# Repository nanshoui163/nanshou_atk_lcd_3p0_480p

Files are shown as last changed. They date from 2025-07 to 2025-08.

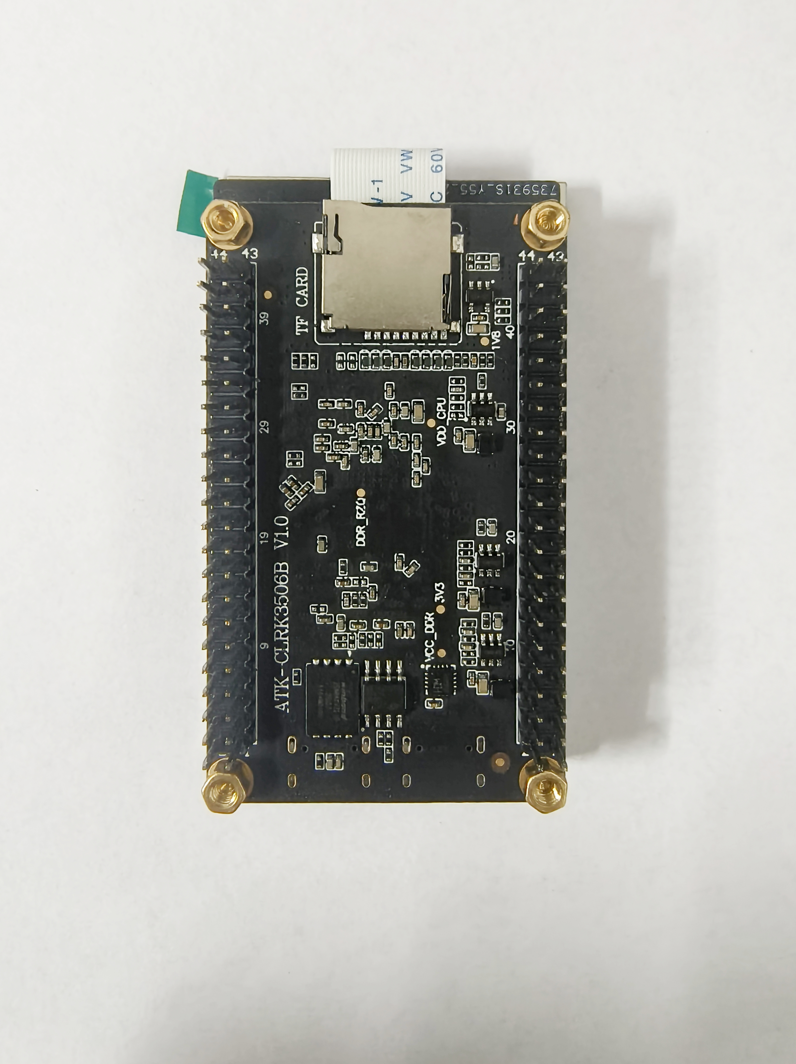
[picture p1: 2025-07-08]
Image/IMG_20250706_234012.jpg

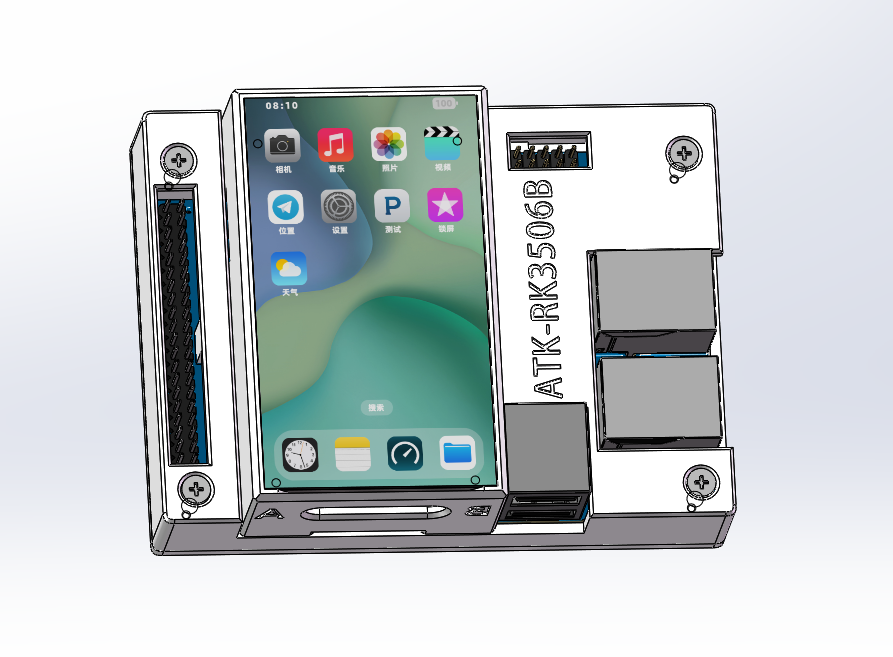
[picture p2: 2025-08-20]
Image/渲染图.png

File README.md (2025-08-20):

# 自制屏幕屏幕-适配正点原子mipi接口的开发板

## 前言

我制作了一款适配正点原子开发板的屏幕模块。可以完美契合rk3506开发板。理论上可以支持正点原子的所有26pin的mipi接口的开发板（待测试）。

采用立创eda设计的pcb，可以直接白嫖。

不玩套路，资料全部开源！！！

走过路过，点个赞吧！

觉得不错的话，点个关注。谢谢大家。

**优秀的工程师都是不吝啬自己的夸奖的，觉得有用的点个赞吧**

# 开源及资料

b站演示视频：

https://www.bilibili.com/video/BV1Jr3ezkEjP

外壳演示链接：

https://www.bilibili.com/video/BV1ZvePzyEGZ/

## 开源链接：

硬件链接：https://oshwhub.com/nanshou/atk_3inch_screen

# 硬件信息

## 屏幕参数

型号：D300T9307V1

尺寸：3“

分辨率：480*854

外形尺寸：42.64mm*74.41mm

视角：IPS

亮度：360 Cd/m2

显示ic：ST7701S

触摸ic：电容触摸，可能是混批。我的是CST128A

# 食用方法

## 代码

- 方法1：合并patch目录下的补丁。

  ```
  git am xx.patch
  ```

  基于rk3506初版sdk制作的补丁，如果后续原子更新sdk，补丁可能合入失败，则需要手动合入补丁。

- 方法2：参考kernel下的代码，复制/替换对应文件

## 外壳

3d打印或者其他打印方式，参考外壳演示视频https://www.bilibili.com/video/BV1ZvePzyEGZ/

# 注意事项

- 焊接完成，先测电源是否短路再上电。
- mipi不支持热插拔，热插拔可能损坏板卡或屏幕
- 连接排线注意线序、方向，接反可能损坏板卡或屏幕

# 版本信息

### V1.0版本：

实测了rk3506板卡，显示触摸功能正常，可以完美使用。

### V1.1 版本

优化外壳设计

# 总结

理论支持原子其他板卡，如rk3568，rv1126等。时间精力有限，暂时没有测试。

## 参考资料

- 正点原子开源的板卡及其资料，演示ui为正点原子qt程序
- 触摸驱动代码参考：https://gitee.com/fengmoxi/tspi-d395c930uv0/tree/master/cst128a_cust

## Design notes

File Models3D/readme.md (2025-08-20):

# 外壳说明：

### 版本：20250820，v1.2.1

### 文件说明：

- 3inchScreen-ATK-RK3506B-Case_V1.2.1_0820.STEP -- 核心版外壳

- Baseboard_PCB_Enclosure_V1.2.1_0820.STEP -- 底板外壳上部

- Bottom_V1.2.1_0820.STEP -- 底板外壳下部

### 装配说明：

使用如下配件大螺丝及螺母柱固定

- M3*14 螺丝*8
- M3*3 螺丝*4
- M3*6*1 垫片*4
- M3*3.5*5 贴片螺母柱*4，用于屏幕支撑
- M3*6*5.5 贴片螺母柱*4，rk3506底板支撑，原子开发板默认有焊接

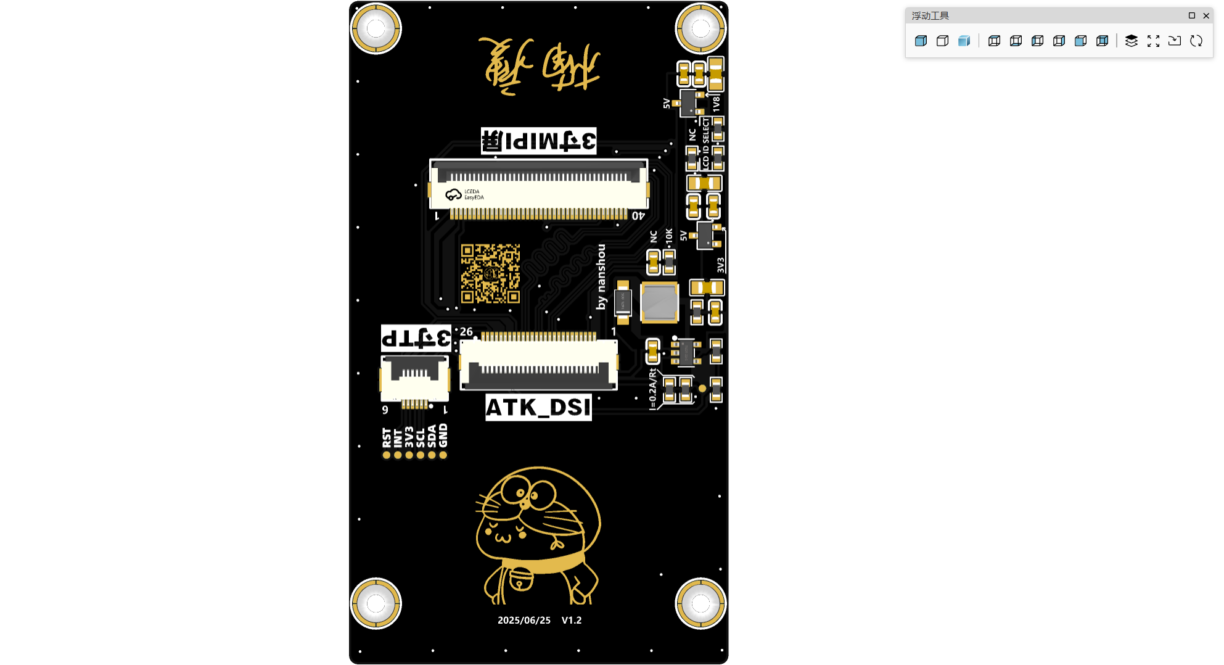
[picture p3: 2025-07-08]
Image/Snipaste_2025-07-06_23-46-10.png

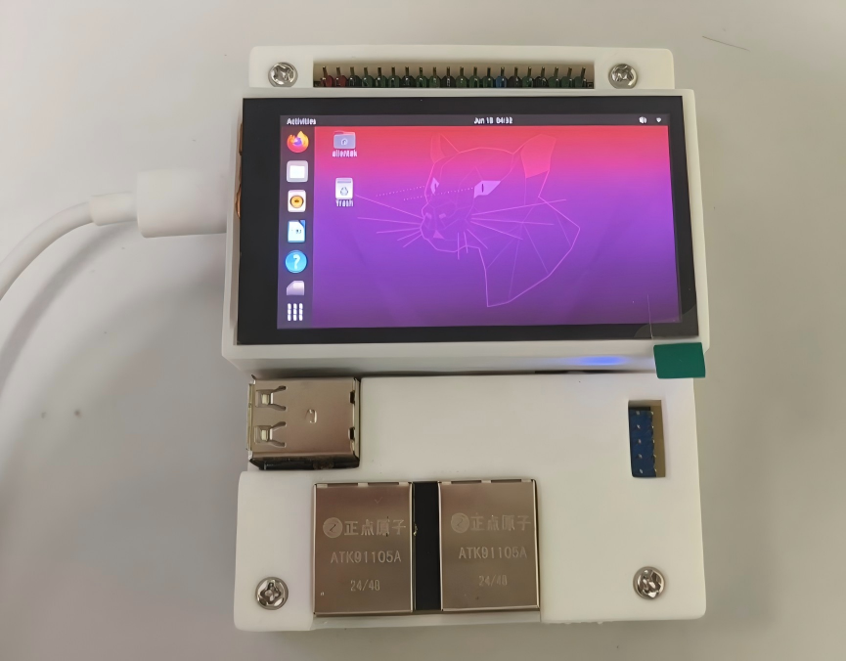
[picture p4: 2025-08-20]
Image/实物图.png

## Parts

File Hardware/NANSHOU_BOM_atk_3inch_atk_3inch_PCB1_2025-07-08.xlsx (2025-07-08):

No. | Quantity | Comment | Designator | Footprint | Value | Manufacturer Part | Manufacturer | Supplier Part | Supplier | Name
1 | 4 | 100nF | C1,C3,C4,C5 | C0603 | 100nF | CC0603KRX7R9BB104 | YAGEO(国巨) | C14663 | LCSC | 100nF
2 | 3 | 47uF | C2,C6,C8 | C0805 | 47uF | CL21A476MQYNNNE | SAMSUNG(三星) | C16780 | LCSC | 47uF
3 | 1 | NC/100nF | C7 | C0603 | NC/100nF | CC0603KRX7R9BB104 | YAGEO(国巨) |  | LCSC | NC/100nF
4 | 2 | 1uF | C9,C10 | C0603 | 1uF | CL10A105KB8NNNC | SAMSUNG(三星) | C15849 | LCSC | 1uF
5 | 4 | SMTWE2030MTJ | CN1,CN2,CN3,CN4 | SMD-1_BD4.4-D2.8 |  | SMTWE2030MTJ | Sinhoo(雄和远景) | C2928179 | LCSC | SMTWE2030MTJ
6 | 1 | FPC-05F-6PH20 | CTP1 | FPC-SMD_6P-P0.50_XUNPU_FPC-05F-6PH20 |  | FPC-05F-6PH20 | XUNPU(讯普) | C2856796 | LCSC | FPC-05F-6PH20
7 | 1 | DSK34 | D1 | SOD-123FL_L2.7-W1.8-LS3.8-RD |  | DSK34 | TWGMC(台湾迪嘉) | C727076 | LCSC | DSK34
8 | 1 | 4.7uH | L1 | IND-SMD_L4.0-W4.0_FNR40XXS | 4.7uH | FNR4030S4R7MT | cjiang(长江微电) | C167874 | LCSC | 4.7uH
9 | 1 | AFC01-S40FCA-00 | LCD1 | FPC-SMD_P0.50-40P_FGS-XJ-H2.0 |  | AFC01-S40FCA-00 | JS(钜硕电子) | C262674 | LCSC | AFC01-S40FCA-00
10 | 3 | 10kΩ | R1,R4,R5 | R0603 | 10kΩ | 0603WAF1002T5E | UNI-ROYAL(厚声) | C25804 | LCSC | 10kΩ
11 | 1 | 5kΩ | R2 | R0603 | 5kΩ | RT0603BRE075KL | YAGEO(国巨) | C862232 | LCSC | 5kΩ
12 | 1 | 100kΩ | R3 | R0603 | 100kΩ | 0603WAF1003T5E | UNI-ROYAL(厚声) | C25803 | LCSC | 100kΩ
13 | 1 | 10Ω | R6 | R0603 | 10Ω | 0603WAF100JT5E | UNI-ROYAL(厚声) | C22859 | LCSC | 10Ω
14 | 1 | 1% | R7 | R0603 | 10Ω | 0603WAJ0100T5E | UNI-ROYAL(厚声) | C25202 | LCSC | 10Ω
15 | 1 | 1% | R8 | R0603 | NC | 0603WAJ0100T5E | UNI-ROYAL(厚声) |  | LCSC | NC
16 | 1 | NC/10kΩ | R9 | R0603 | NC/10kΩ | 0603WAF1002T5E | UNI-ROYAL(厚声) |  | LCSC | NC/10kΩ
17 | 7 | Test-Point | TP1,TP2,TP3,TP4,TP5,TP6,TP7 | Test-Point-0.5mm
18 | 1 | XC6206P332MR | U1 | SOT-23-3_L2.9-W1.6-P1.90-LS2.8-BR |  | XC6206P332MR | YONGYUTAI(永裕泰) | C2897477 | LCSC | XC6206P332MR
19 | 1 | XC6206P182MR(1uA) | U2 | SOT-23-3_L2.9-W1.6-P1.90-LS2.8-BR |  | XC6206P182MR(1uA) | TECH PUBLIC(台舟) | C2827651 | LCSC | XC6206P182MR(1uA)
20 | 1 | MP3302DJ | U3 | TSOT-23-5_L2.9-W1.6-P0.95-LS2.8-BL |  | MP3302DJ |  | C9900002157 | LCSC | MP3302DJ
21 | 1 | AFC01-S26FCA-00 | X1 | FPC-SMD_AFC01-S26FCA-00 |  | AFC01-S26FCA-00 | JS(钜硕电子) | C262670 | LCSC | AFC01-S26FCA-00

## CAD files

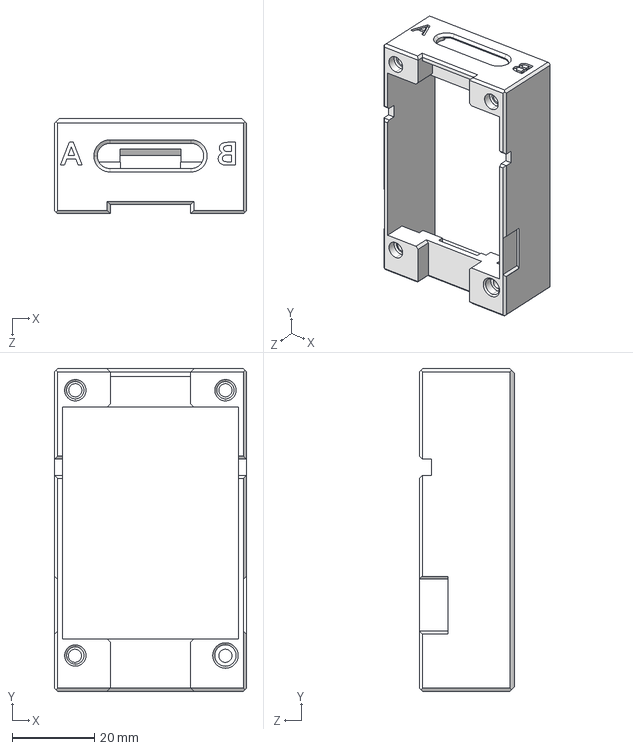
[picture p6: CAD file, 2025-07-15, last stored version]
Models3D/3inchScreen-ATK-RK3506B-Case-V1.2-20250714.STEP
46.8 x 78.5 x 23.2 mm

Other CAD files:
Models3D/3inchScreen-ATK-RK3506B-Case-V1.2-20250714.gcode.3mf
Models3D/3inchScreen-ATK-RK3506B-Case-V1.2-20250714.3mf

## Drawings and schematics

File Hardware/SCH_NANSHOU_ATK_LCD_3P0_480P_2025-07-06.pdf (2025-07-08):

10 10 11 11 12 12 13 13 14 14 15 15 16 16 17 17 18 18 19 19 20 20 21 21 22 22 23 23 24 24 25 25 26 26 27 27 28 28 29 29 30 30 31 31 32 32 33 33 34 34 35 35 36 36 37 37 38 38 39 39 40 40

# 3寸屏幕TP

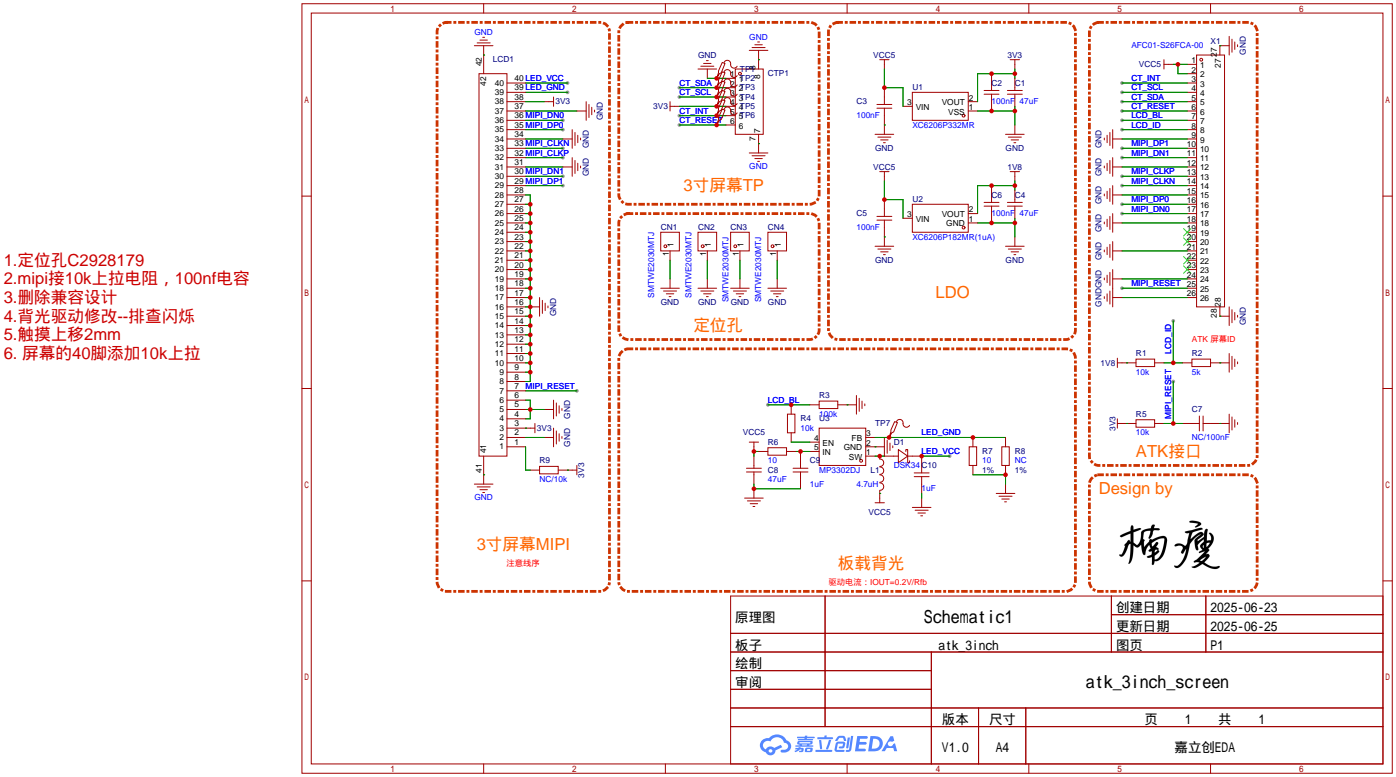
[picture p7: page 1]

GND GND GND GND GND GND GND

原理图 | Schematic1 | 创建日期 | 2025-06-23

更新日期 | 2025-06-25

板子 | atk_3inch | 图页 | P1
绘制 | | atk_3inch_screen
审阅

V1.0 | A4 | 嘉立创EDA

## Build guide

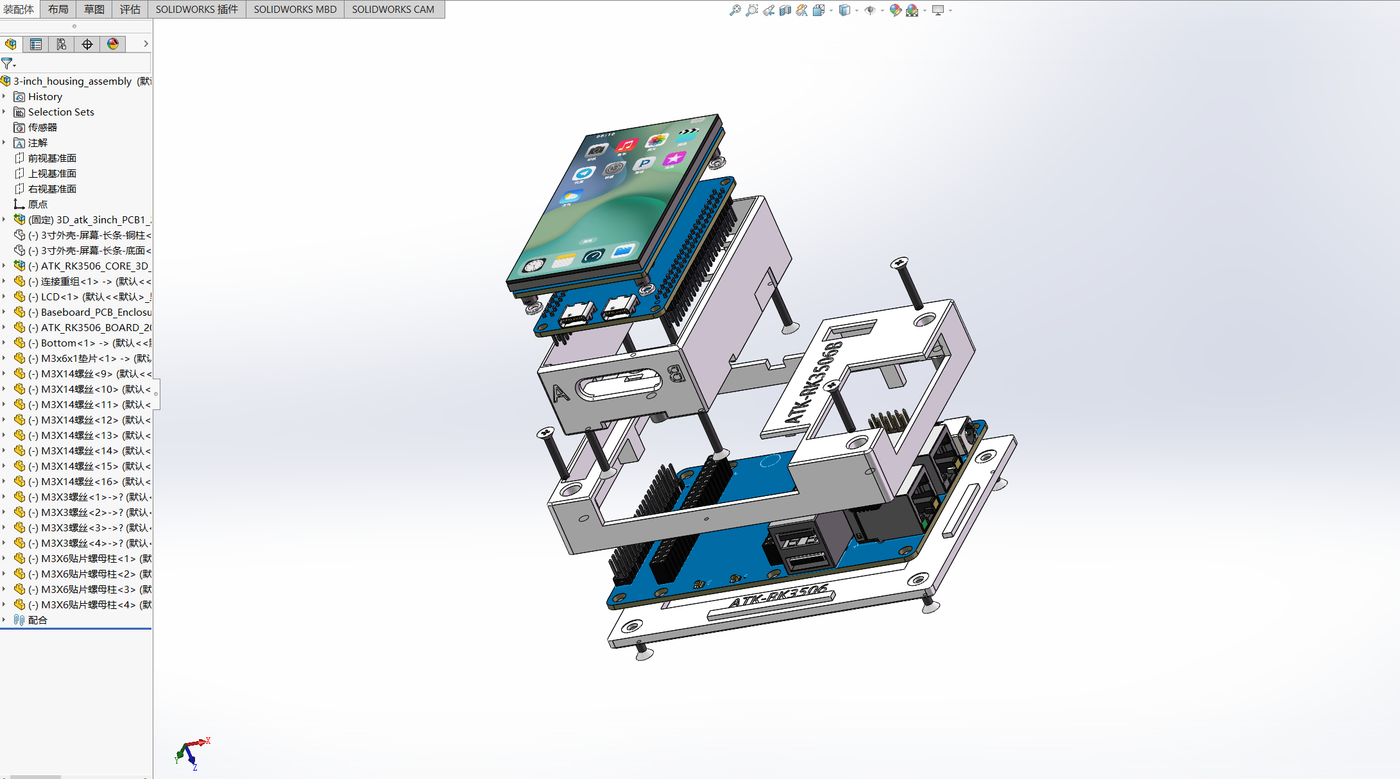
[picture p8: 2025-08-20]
Image/装配图.png

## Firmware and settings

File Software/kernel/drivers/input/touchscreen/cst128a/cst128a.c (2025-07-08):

/****************************************************************
* Driver modified from FocalTech driver
* Reference: ALIENTEK, leefei
****************************************************************/
#include <linux/module.h>
#include <linux/i2c.h>
#include <linux/input/mt.h>
#include <linux/of_gpio.h>
#include <linux/delay.h>
#include <linux/interrupt.h>

#define SCREEN_WIDTH  480
#define SCREEN_HEIGHT 854


/* CST128 register definitions */
#define MAX_SUPPORT_POINTS 5       // Max 5 touch points supported
#define CST128_DEVIDE_MODE_REG 0x00 // Mode register
#define CST128_TD_STATUS_REG   0x02 // Status register
#define CST128_TOUCH_DATA_REG  0x03 // Touch data start register
#define CST128_ID_G_MODE_REG   0xA4 // Interrupt mode register

/* Touch event types */
#define TOUCH_EVENT_DOWN      0x00
#define TOUCH_EVENT_UP        0x01
#define TOUCH_EVENT_ON        0x02
#define TOUCH_EVENT_RESERVED  0x03

struct hyn_cst128_dev {
    struct i2c_client *client;
    struct input_dev *input;
    int reset_gpio;
    int irq_gpio;
};

#define E_LOG(fmt, args...) printk(KERN_ERR "[CST128A/E]%s:" fmt "\n", __func__, ##args)

/* I2C write operation */
static int hyn_cst128_write(struct hyn_cst128_dev *cst128, u8 addr, u8 *buf, u16 len)
{
    struct i2c_client *client = cst128->client;
    struct i2c_msg msg;
    u8 send_buf[6] = { 0 };
    int ret;

    send_buf[0] = addr;
    memcpy(&send_buf[1], buf, len);
    msg.flags = 0;
    msg.addr = client->addr;
    msg.buf = send_buf;
    msg.len = len + 1;

    ret = i2c_transfer(client->adapter, &msg, 1);
    if (ret != 1) {
        dev_err(&client->dev, "Write error, addr=0x%x len=%d\n", addr, len);
        return -1;
    }
    return 0;
}

/* I2C read operation */
static int hyn_cst128_read(struct hyn_cst128_dev *cst128, u8 addr, u8 *buf, u16 len)
{
    struct i2c_client *client = cst128->client;
    struct i2c_msg msg[2];
    int ret;

    msg[0].flags = 0; // Write
    msg[0].addr = client->addr;
    msg[0].buf = &addr;
    msg[0].len = 1;

    msg[1].flags = I2C_M_RD; // Read
    msg[1].addr = client->addr;
    msg[1].buf = buf;
    msg[1].len = len;

    ret = i2c_transfer(client->adapter, msg, 2);
    if (ret != 2) {
        dev_err(&client->dev, "Read error, addr=0x%x len=%d\n", addr, len);
        return -1;
    }
    return 0;
}

/* Reset touch controller */
static int hyn_cst128_reset(struct hyn_cst128_dev *cst128)
{
    struct i2c_client *client = cst128->client;
    int ret;

    cst128->reset_gpio = of_get_named_gpio(client->dev.of_node, "reset-gpios", 0);
    if (!gpio_is_valid(cst128->reset_gpio)) {
        dev_err(&client->dev, "Invalid reset GPIO\n");
        return cst128->reset_gpio;
    }

    ret = devm_gpio_request_one(&client->dev, cst128->reset_gpio,
                               GPIOF_OUT_INIT_HIGH, "cst128 reset");
    if (ret < 0) 
    {
        dev_err(&client->dev, "gpio request error\n");
        return ret;
    }

    msleep(20);
    gpio_set_value_cansleep(cst128->reset_gpio, 0);
    msleep(15);
    gpio_set_value_cansleep(cst128->reset_gpio, 1);

    return 0;
}

/* Interrupt handler for touch events */
static irqreturn_t hyn_cst128_isr(int irq, void *dev_id)
{
	struct hyn_cst128_dev *cst128 = dev_id;
	u8 rdbuf[30] = { 0 };
	int i, type, x, y, id;
	bool down;
	int ret;

	/* Read CST128 touch coordinates starting from register 0x02, continuously read 30 registers */
	ret = hyn_cst128_read(cst128, CST128_TD_STATUS_REG, rdbuf, 30);
	if (ret)
		goto out;

	for (i = 0; i < MAX_SUPPORT_POINTS; i++) {
		u8 *buf = &rdbuf[i * 6 + 1];

		/* Taking the first touch point as example, register TOUCH1_XH (address 0x03), bit description:
         * bit7:6  Event flag  0:Press down 1:Release 2:Contact 3:No event
         * bit5:4  Reserved
         * bit3:0  X-axis touch point bits [11:8]
         */
		type = buf[0] >> 6; // Get touch point's Event Flag
		if (type == TOUCH_EVENT_RESERVED)
			continue;

		x = ((((buf[0] & 0x0f) << 8) | buf[1]) & 0x0fff);
		y = (((buf[2] & 0x0f) << 8) | buf[3]) & 0x0fff;

		if (x == 0 || y == 0 || x >= SCREEN_WIDTH || y >= SCREEN_HEIGHT)
			continue;
		x = SCREEN_WIDTH - x;

		/* Taking the first touch point as example, register TOUCH1_YH (address 0x05), bit description:
         * bit7:4  Touch ID  Identifies which touch point
         * bit3:0  Y-axis touch point bits [11:8]
         */
		id = (buf[2] >> 4) & 0x0f;
		down = type != TOUCH_EVENT_UP;

		input_mt_slot(cst128->input, id);
		input_mt_report_slot_state(cst128->input, MT_TOOL_FINGER, down);

		if (!down)
			continue;
		//E_LOG("position x=%d,y=%d", x, y);
		input_report_abs(cst128->input, ABS_MT_POSITION_X, x);
		input_report_abs(cst128->input, ABS_MT_POSITION_Y, y);
	}

	input_mt_report_pointer_emulation(cst128->input, true);
	input_sync(cst128->input);

out:
	return IRQ_HANDLED;
}

/* Initialize interrupt handling */
static int hyn_cst128_irq(struct hyn_cst128_dev *cst128)
{
    struct i2c_client *client = cst128->client;
    int ret;

    cst128->irq_gpio = of_get_named_gpio(client->dev.of_node, "irq-gpios", 0);
    if (!gpio_is_valid(cst128->irq_gpio)) {
        dev_err(&client->dev, "Invalid IRQ GPIO\n");
        return cst128->irq_gpio;
    }

    ret = devm_gpio_request_one(&client->dev, cst128->irq_gpio, 
                               GPIOF_IN, "cst128 interrupt");
    if (ret < 0) return ret;

    ret = devm_request_threaded_irq(&client->dev,
                                  gpio_to_irq(cst128->irq_gpio), NULL,
                                  hyn_cst128_isr,
                                  IRQF_TRIGGER_FALLING | IRQF_ONESHOT,
                                  client->name, cst128);
    if (ret) {
        dev_err(&client->dev, "Failed to request IRQ\n");
        return ret;
    }

    return 0;
}
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

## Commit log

2025-07-08 init v1.0
    [NANSHOU_BOM_atk_3inch_atk_3inch_PCB1_2025-07-08.xlsx]
2025-07-15 Add Models3D and Gerber.zip
    [3inchScreen-ATK-RK3506B-Case-V1.2-20250714.3mf, 3inchScreen-ATK-RK3506B-Case-V1.2-20250714.STEP, 3inchScreen-ATK-RK3506B-Case-V1.2-20250714.gcode.3mf]
2025-08-20 update Models3D and Image, v1.1
    [3inchScreen-ATK-RK3506B-Case-V1.2-20250714.3mf, 3inchScreen-ATK-RK3506B-Case-V1.2-20250714.STEP, 3inchScreen-ATK-RK3506B-Case-V1.2-20250714.gcode.3mf]
